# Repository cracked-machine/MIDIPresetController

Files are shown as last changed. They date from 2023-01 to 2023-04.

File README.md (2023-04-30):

# MIDIPresetController

This is a simple MIDI controller for Guitar FX pedals. An [STM32L011D4](HW/techdocs/stm32l011d4_datasheet.pdf) is used to detect stomp switch presses by the user and output MIDI signals via a DIN5 connector.

The project is designed to fit into a [Hammond 1455J1602](HW/techdocs/Hammond_1455J1602BK_enclosure.pdf) enclosure. 

3D models can be found here for the [end plate bezel](https://3dviewer.net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) and [main extrusion](https://3dviewer.net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)

This is an extruded alu case. The PCB slides in from one side.  

The stomp switches are panel mounted on the front side of the enclosure with connecting wires to rear of the PCB (via molex KK254 connectors)





It is powered by a 3v3 CR2032 cell, held by a battery clip, which is mounted on the rear side of the PCB. Internal voltage reference of the MCU is used to measure remaining battery. An LED mounted on the front of the PCB and connected to GPIO indicates low battery power to the user.

The MIDI channel can be selected using the DIP switch on the rear side of the PCB.  The MIDI output connector (DIN5) is mounted to the end plate bezel of the enclosure

A 10-pin ARM SWD programming connector is mounted to the rear of the PCB. 

A removable "belly plate" on the enclosure provides access to the battery, MIDI DIP switch and SWD connector.  

### Development Environment

YOu can run this project from within a container and program the board via a Segger JLink. This uses `JLinkRemoteServer` to establish a connect between the container environment and the device connected to the `host` PC. To enable this connection, run the follow command on the __host__ terminal:

```
JLinkRemoteServer --select USB
```

See [stm32_dev_docker/README.md](https://github.com/cracked-machine/stm32_dev_docker) for instructions on using the `development environment` for this project.

Note: this project is currently configured for a specific version of CMake and ARM compiler. The paths are hard-coded in the project [here](.vscode/settings.json)

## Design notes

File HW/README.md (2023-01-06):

# MIDIPresetController

This is the doc for the [hardware project files](KicadProject)

This project has the following dependencies to [KicadLibrary](HW/KicadLibrary):

- BATTERY/GenericCoinCellHolders/GenericCoinCellHolders

## Schematic 

1. System



2. Input 



3. MCU



4. Output



## Pinout 
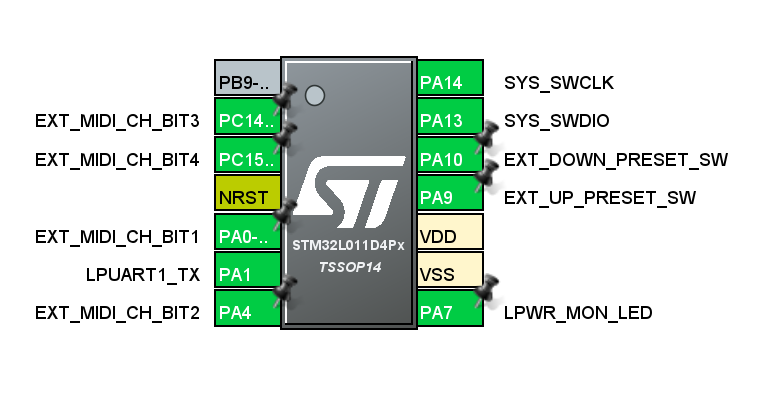
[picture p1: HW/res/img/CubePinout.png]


## PCB

1. Front

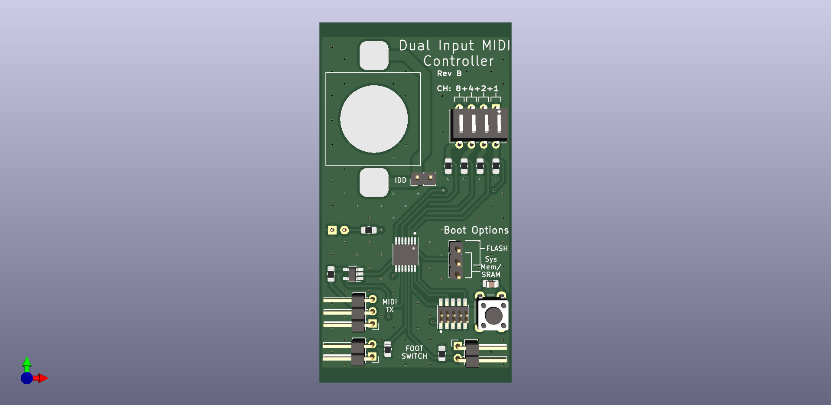
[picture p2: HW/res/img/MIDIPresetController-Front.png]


2. Back

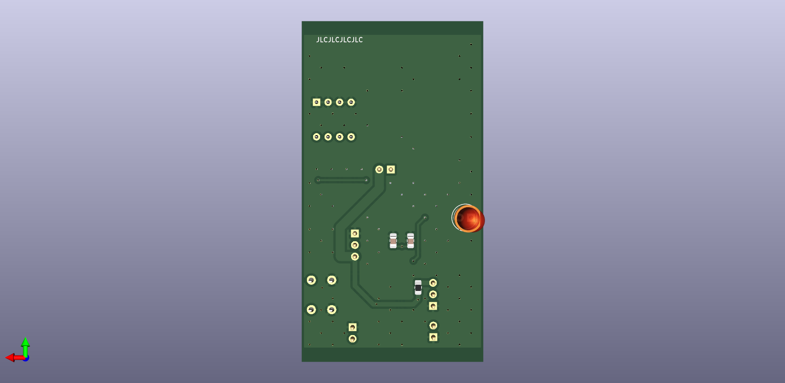
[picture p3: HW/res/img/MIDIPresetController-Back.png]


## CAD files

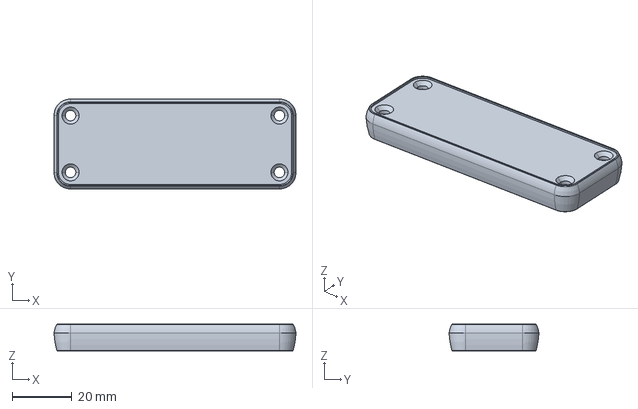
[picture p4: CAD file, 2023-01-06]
HW/res/3d/1455J1602/J Bezel Closed.stp
81.1 x 30.1 x 9.00 mm

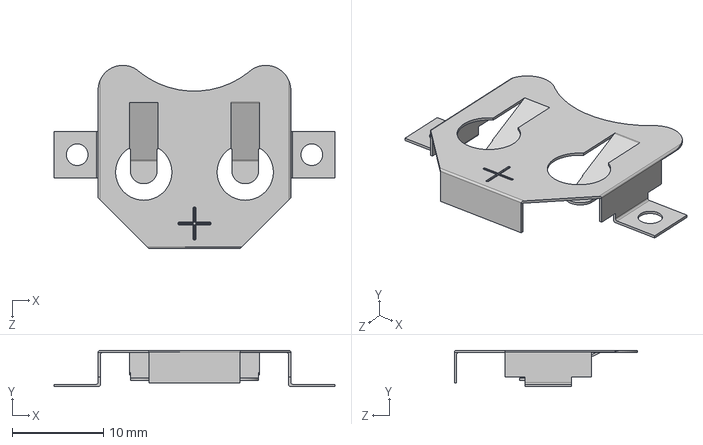
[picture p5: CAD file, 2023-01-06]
HW/res/3d/CR3Holder002.step
30.7 x 3.96 x 20.1 mm

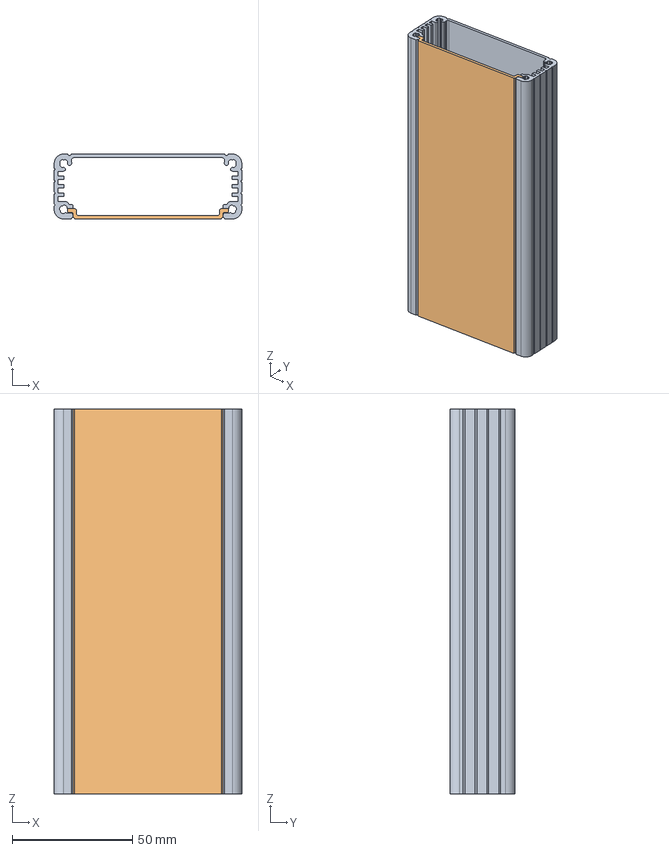
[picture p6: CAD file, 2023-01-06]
HW/res/3d/1455J1602/J Extrusion 160mm.stp
78.0 x 27.0 x 160.0 mm

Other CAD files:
HW/res/3d/1455J1602/J Bezel Closed.igs
HW/res/3d/1455J1602/J Extrusion 160mm.igs

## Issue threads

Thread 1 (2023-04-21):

Enable timer for debounce

cracked-machine, 2023-04-21:
1. Enable TIM21 peripheral.  Interrupts are not needed.

```
    RCC->APB2ENR |= RCC_APB2ENR_TIM21EN_Msk;                            // enable the APB2 bus clock used by TIM21
    TIM21->CR1 |= (TIM_CR1_ARPE_Msk);                                   // preload buffer
    TIM21->PSC = 0xFFFF;                                                    // prescaler
    TIM21->ARR = 0xFFFFFFFE;                                            // auto-reload value

    // TIM21->DIER |= (TIM_DIER_UIE_Msk);                                  // enable interrupts
    // NVIC_EnableIRQ(TIM21_IRQn);
    // NVIC_SetPriority(TIM21_IRQn,_TIM21_ISR_PRIORITY);

    TIM21->CR1 |= (TIM_CR1_CEN_Msk);                                    // start the timer
```

2. Add debounce code

```
# global vars
const volatile uint32_t FOOTSW_DEBOUNCE_COOLDOWN{ 100 };
volatile uint32_t footsw_down_prev_cnt = 0;

void PERIPH_ISR()
{
        uint32_t tmp_cnt = TIM21->CNT;
        if ((tmp_cnt - footsw_down_prev_cnt) > FOOTSW_DEBOUNCE_COOLDOWN)
        {
            // do stuff
        }
        footsw_down_prev_cnt = tmp_cnt;

}
```

cracked-machine, 2023-04-21:
f452b76562065cfc2fa9082e9c51a1b93853bc89
e565cd7474d71bd6fbaafc158bc97176621c218a

Closed 2023-04-21.

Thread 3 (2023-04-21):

Enable VREF for battery level monitoring

cracked-machine, 2023-04-21:

cracked-machine, 2023-04-21:
LED should flash when low battery threshold is reached.

- The internal voltage reference (V REFINT ) provides a stable (bandgap) voltage output for the
ADC and comparators. V REFINT is internally connected to the ADC V IN[17] input channel.

- VREFEN bit must be set to enable the conversion of ADC V IN[17] (V REFINT).
- During the manufacturing process, the calibration data of the temperature sensor and the
internal voltage reference are stored in the system memory area. The user application can
then read them and use them to improve the accuracy of the temperature sensor or the
internal reference.

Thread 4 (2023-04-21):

Enable low power mode

cracked-machine, 2023-04-21:
- STOP mode lowers current consumption to ~0.5uA.
- Can be woken from EXTI (i.e. footswitch). Possible startup delay.

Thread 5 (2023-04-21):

Fit TVS diodes to footswitch and dipswitch inputs

cracked-machine, 2023-04-21:

Closed 2023-04-30.

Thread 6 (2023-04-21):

Move `J3` footprint away from NRST `SW1` footprint.

cracked-machine, 2023-04-21:
- Workaround: It is still possible to plug debug cable into `J3` without it being obstructed by `SW1`.

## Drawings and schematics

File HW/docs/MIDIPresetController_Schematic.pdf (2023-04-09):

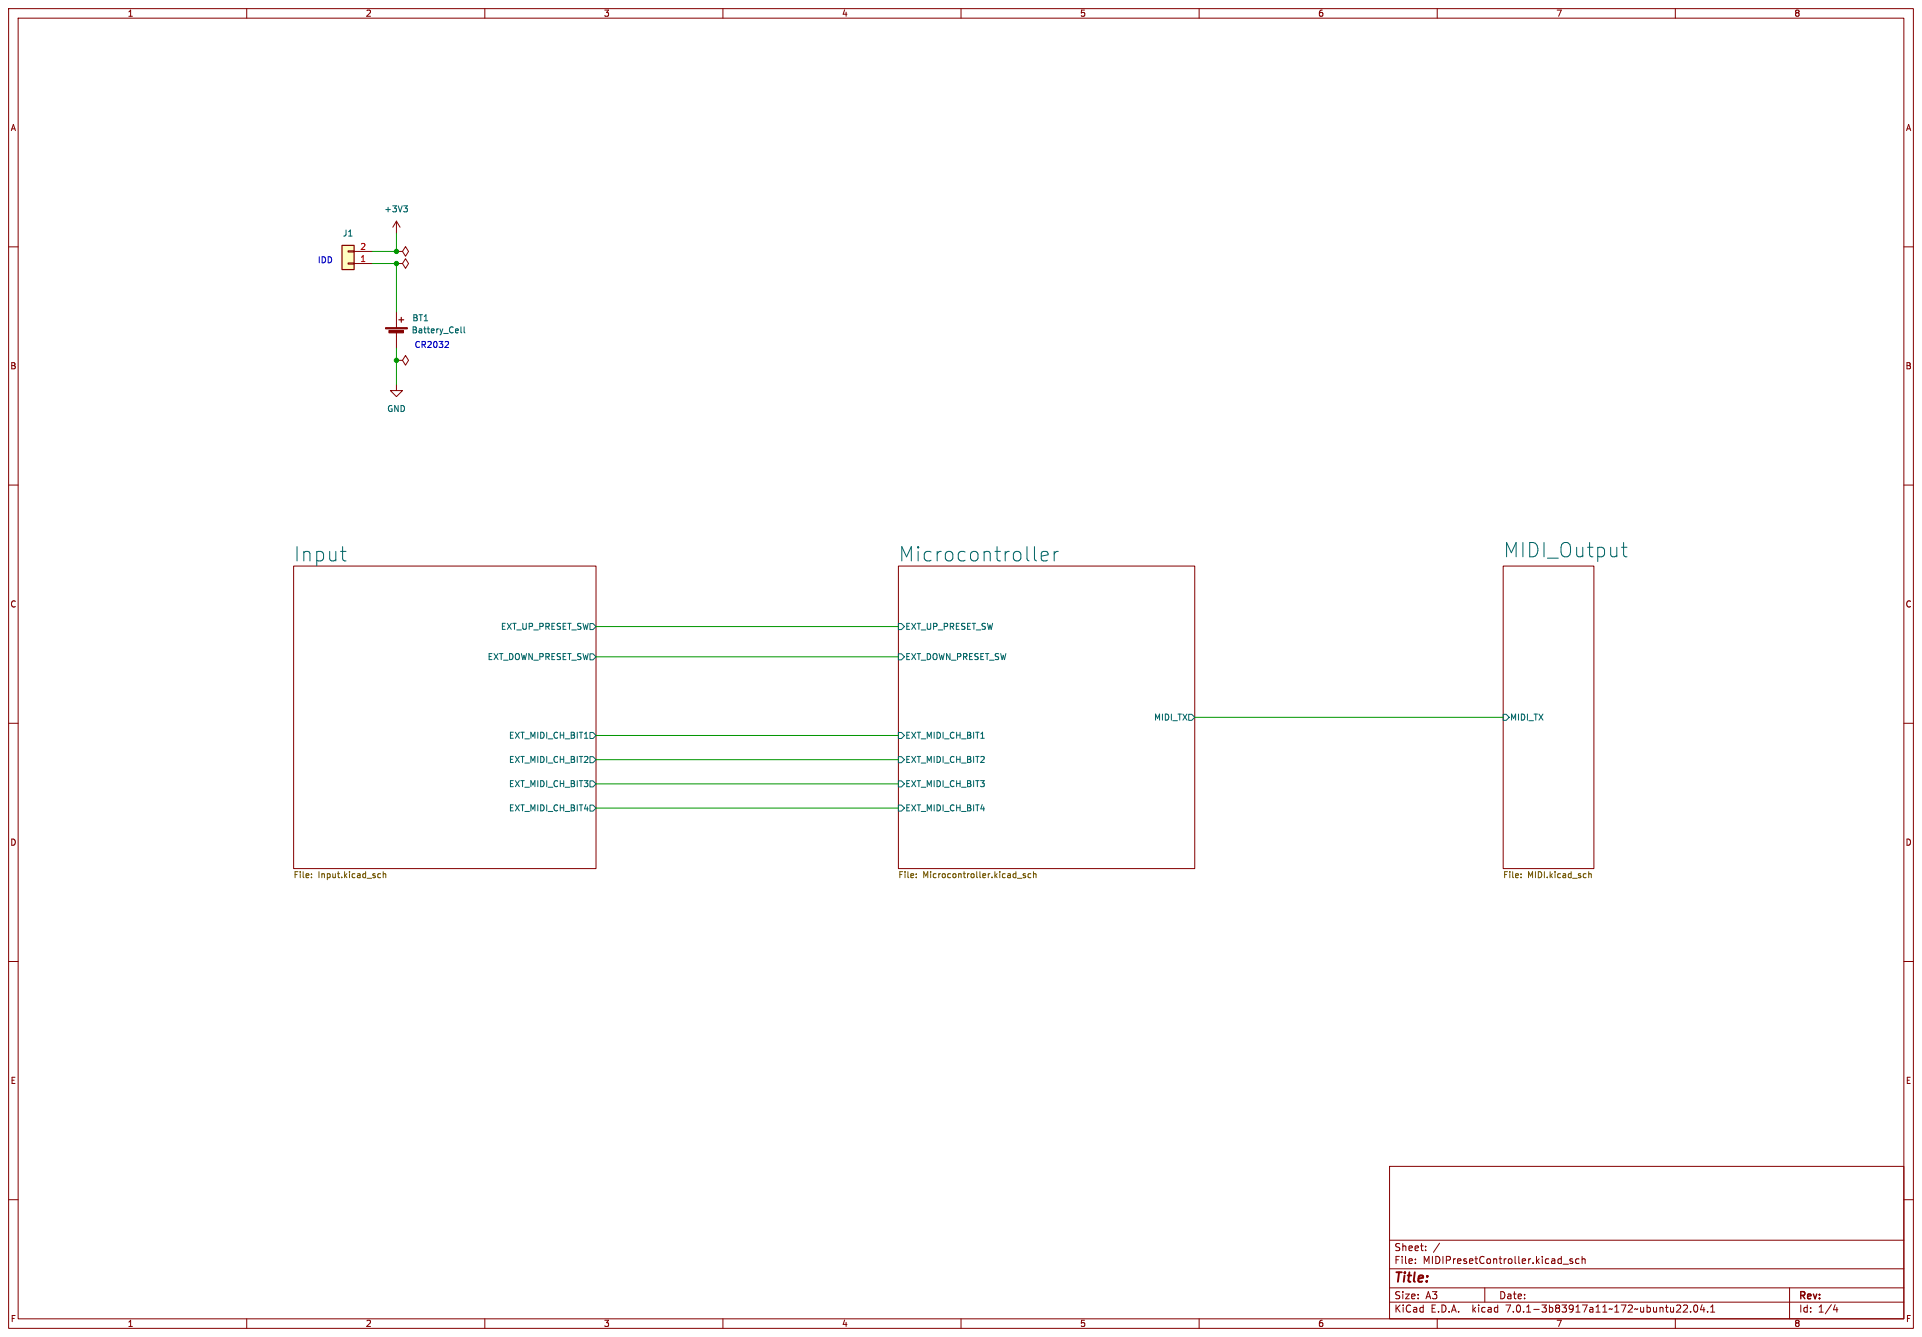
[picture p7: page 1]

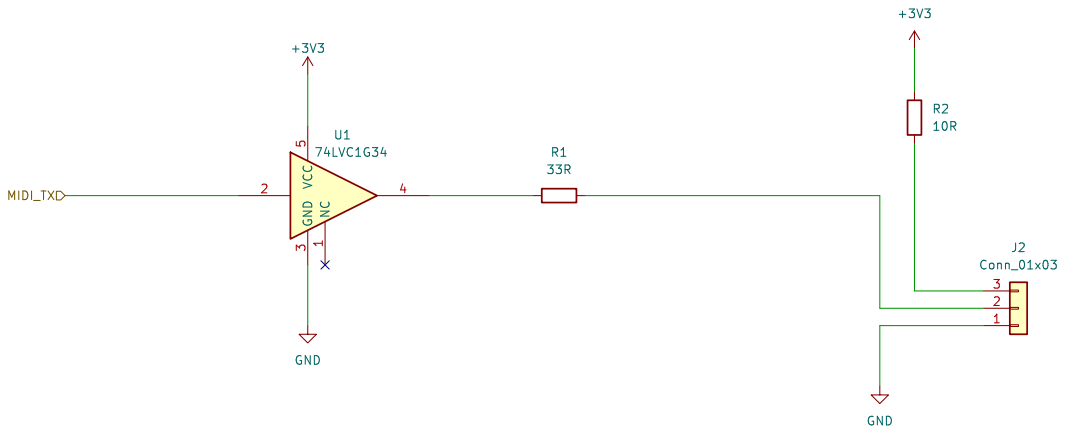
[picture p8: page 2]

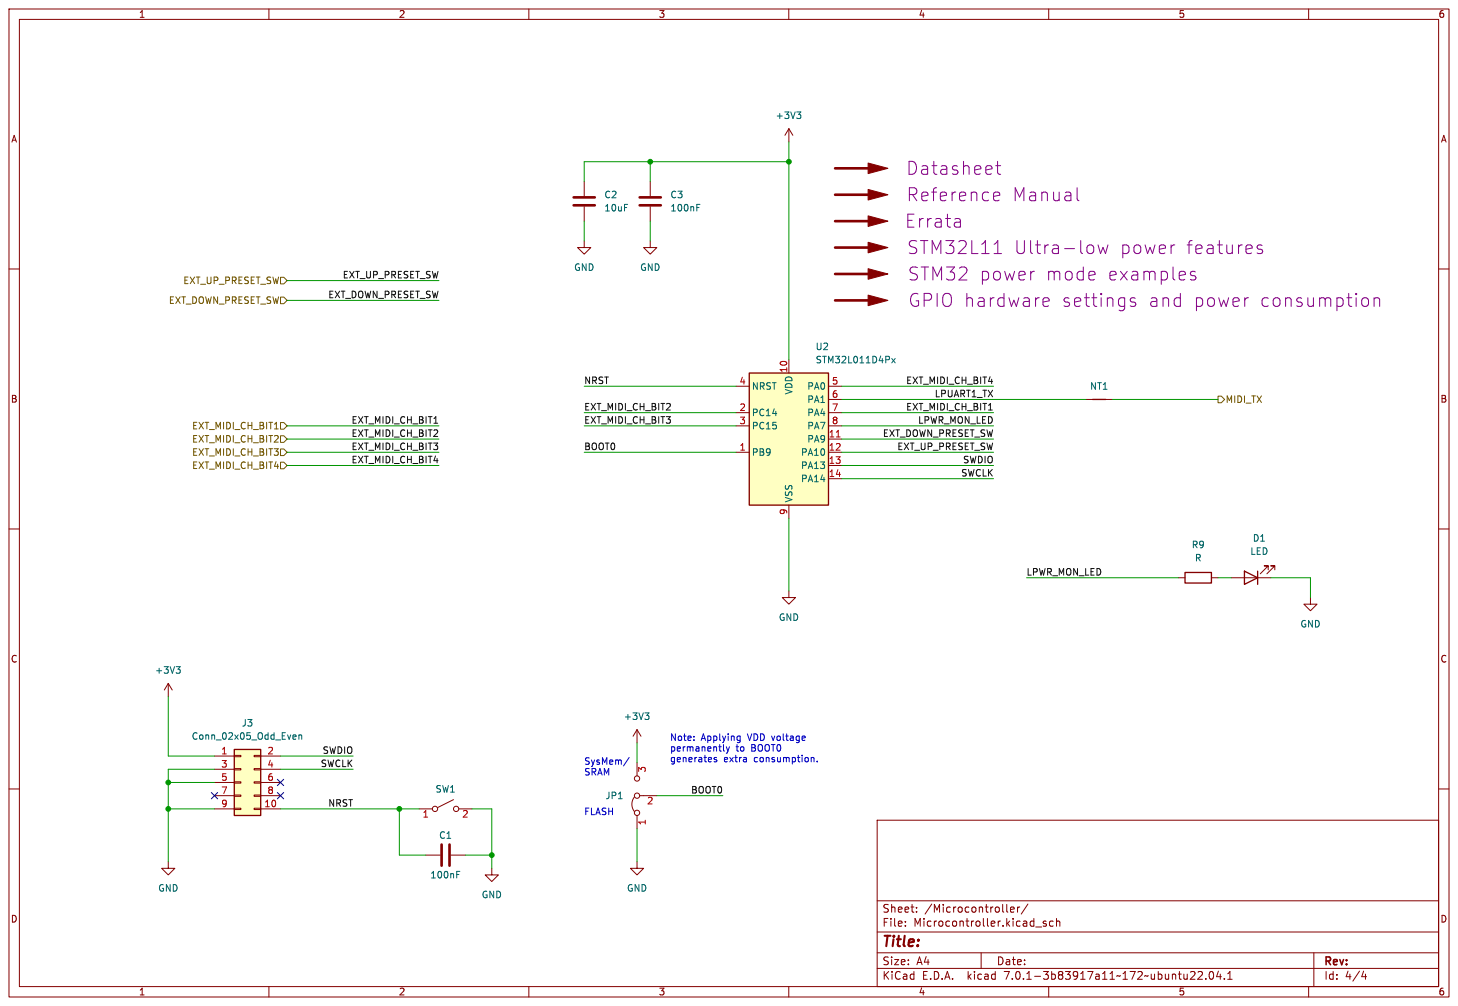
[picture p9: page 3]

Note: Applying VDD voltage

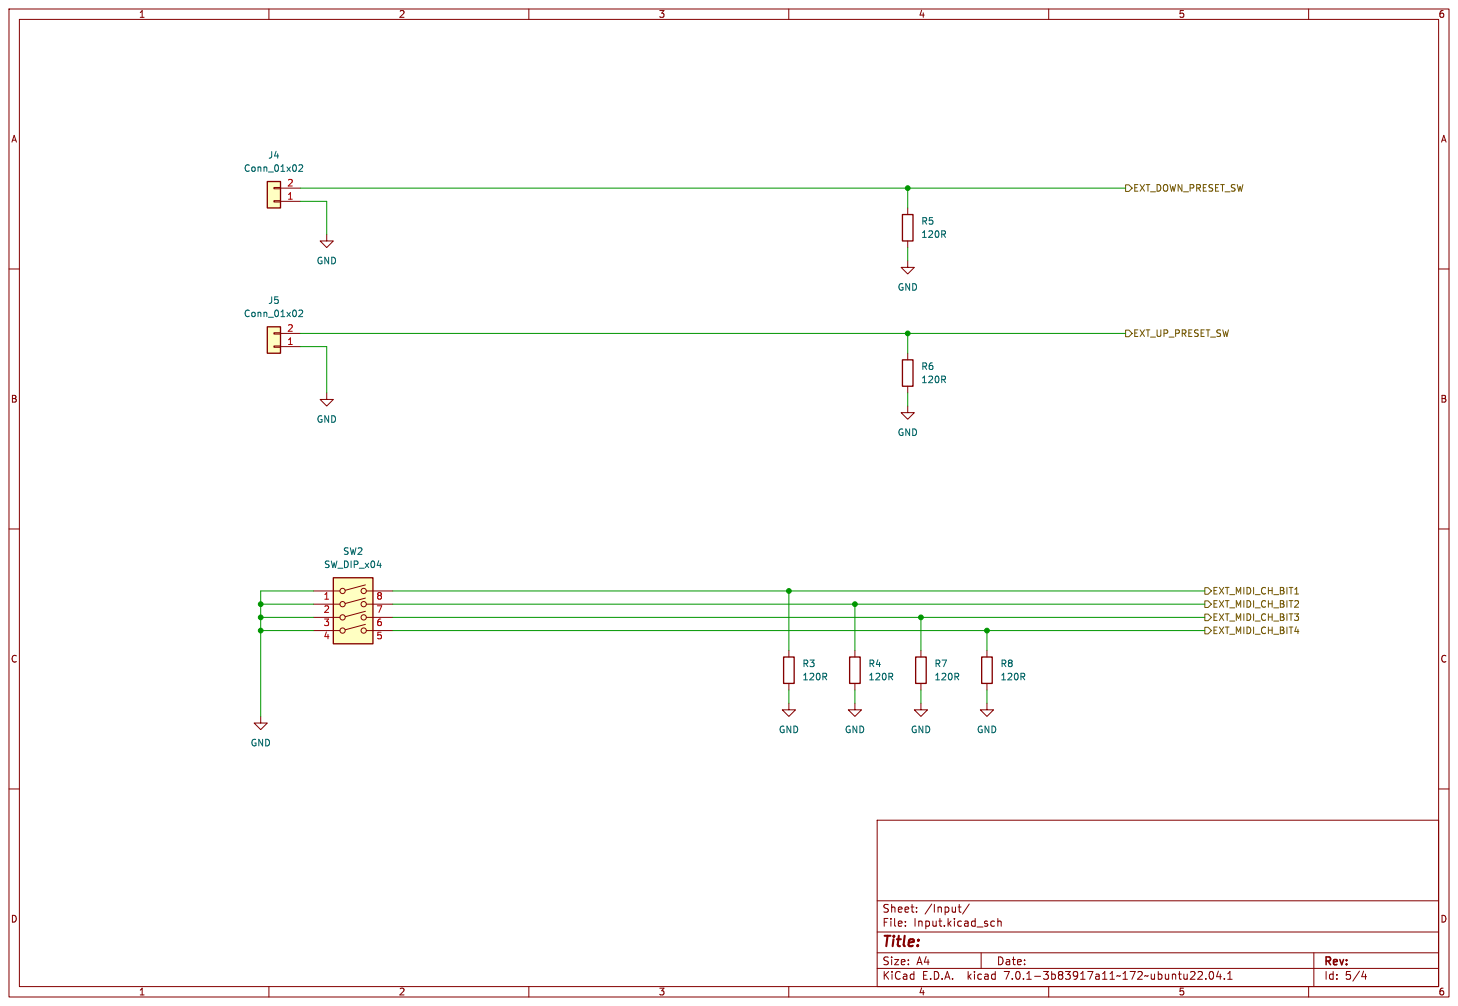
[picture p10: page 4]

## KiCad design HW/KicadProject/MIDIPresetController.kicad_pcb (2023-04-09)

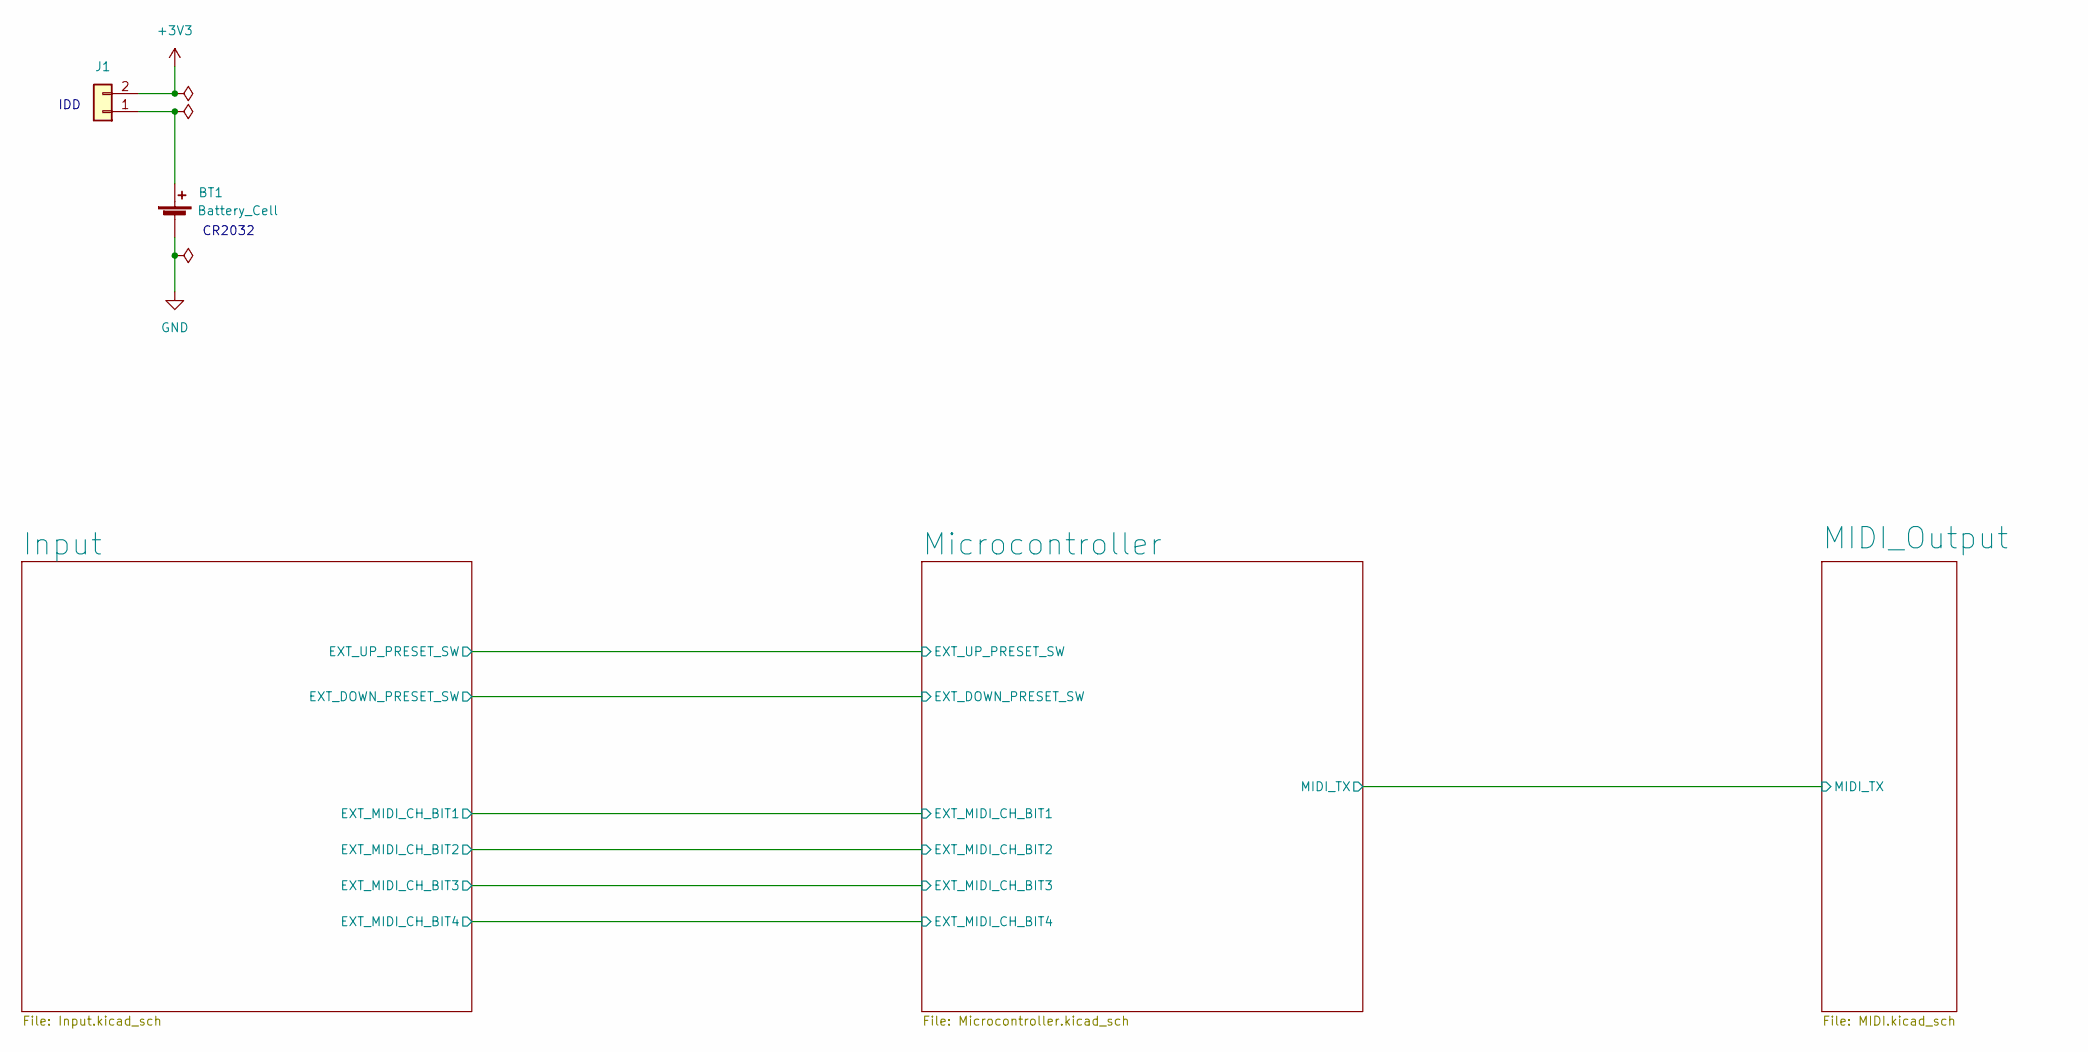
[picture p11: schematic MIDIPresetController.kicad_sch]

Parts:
BT1: Battery_Cell; CR2032
J1: Conn_01x02; PinHeader_1x02_P2.54mm_Vertical

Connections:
+3V3: J1.2; also elsewhere on the board
GND: BT1.2 (-); also elsewhere on the board
unnamed: BT1.1 (+), J1.1

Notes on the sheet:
CR2032
IDD

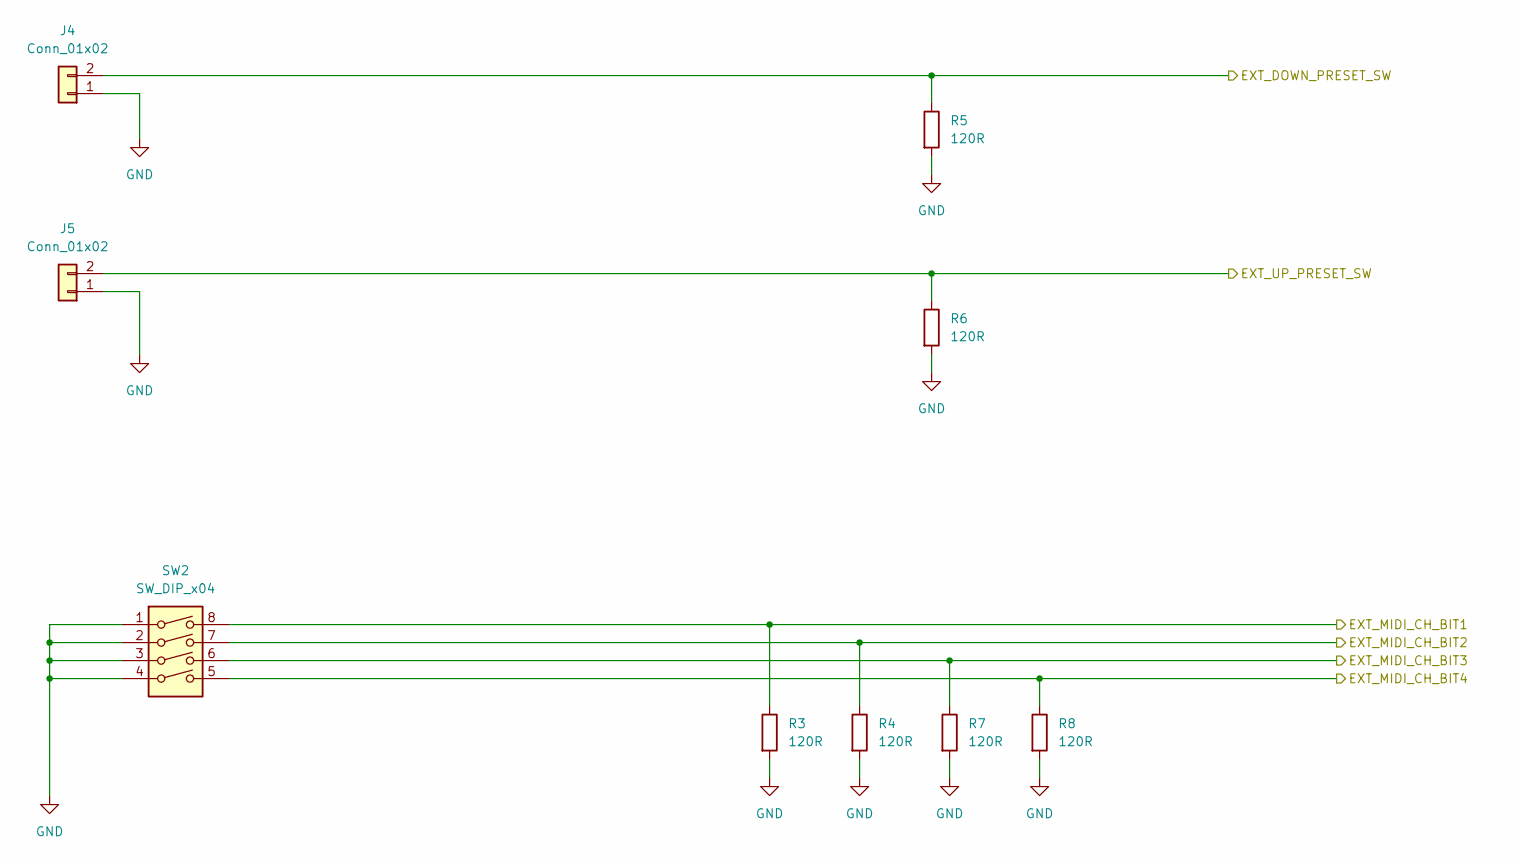
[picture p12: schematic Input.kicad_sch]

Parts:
J4, J5: Conn_01x02; PinHeader_1x02_P2.54mm_Horizontal
R3, R4, R5, R6, R7, R8: 120R; R_0805_2012Metric_Pad1.20x1.40mm_HandSolder
SW2: SW_DIP_x04; SW_DIP_SPSTx04_Slide_6.7x11.72mm_W7.62mm_P2.54mm_LowProfile

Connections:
/Microcontroller/EXT_DOWN_PRESET_SW: J4.2, R5.1; also elsewhere on the board
/Microcontroller/EXT_MIDI_CH_BIT1: R3.1, SW2.8; also elsewhere on the board
/Microcontroller/EXT_MIDI_CH_BIT2: R4.1, SW2.7; also elsewhere on the board
/Microcontroller/EXT_MIDI_CH_BIT3: R7.1, SW2.6; also elsewhere on the board
/Microcontroller/EXT_MIDI_CH_BIT4: R8.1, SW2.5; also elsewhere on the board
/Microcontroller/EXT_UP_PRESET_SW: J5.2, R6.1; also elsewhere on the board
GND: J4.1, J5.1, R3.2, R4.2, R5.2, R6.2, R7.2, R8.2, SW2.1, SW2.2, SW2.3, SW2.4; also elsewhere on the board

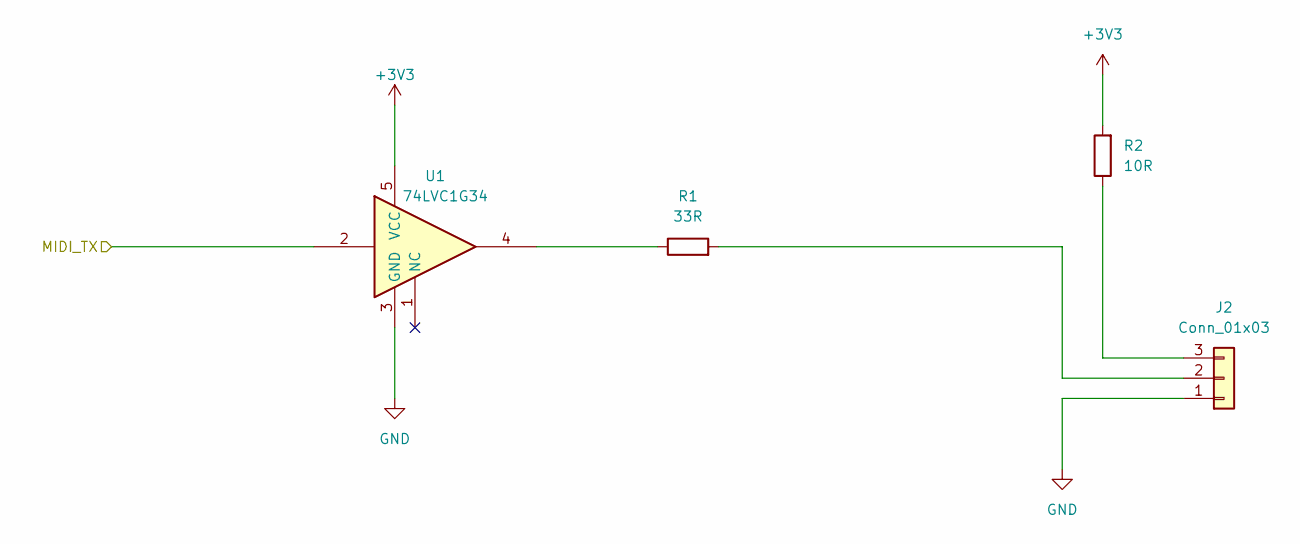
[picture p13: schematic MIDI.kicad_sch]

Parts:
J2: Conn_01x03; PinHeader_1x03_P2.54mm_Horizontal
R1: 33R; R_0805_2012Metric_Pad1.20x1.40mm_HandSolder
R2: 10R; R_0805_2012Metric_Pad1.20x1.40mm_HandSolder
U1: 74LVC1G34; SOT-23-5_HandSoldering

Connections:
+3V3: R2.2, U1.5 (VCC); also elsewhere on the board
/MIDI_Output/MIDI_TX: U1.2; also elsewhere on the board
GND: J2.1, U1.3 (GND); also elsewhere on the board
unnamed: J2.2, R1.2
unnamed: J2.3, R2.1
unnamed: R1.1, U1.4

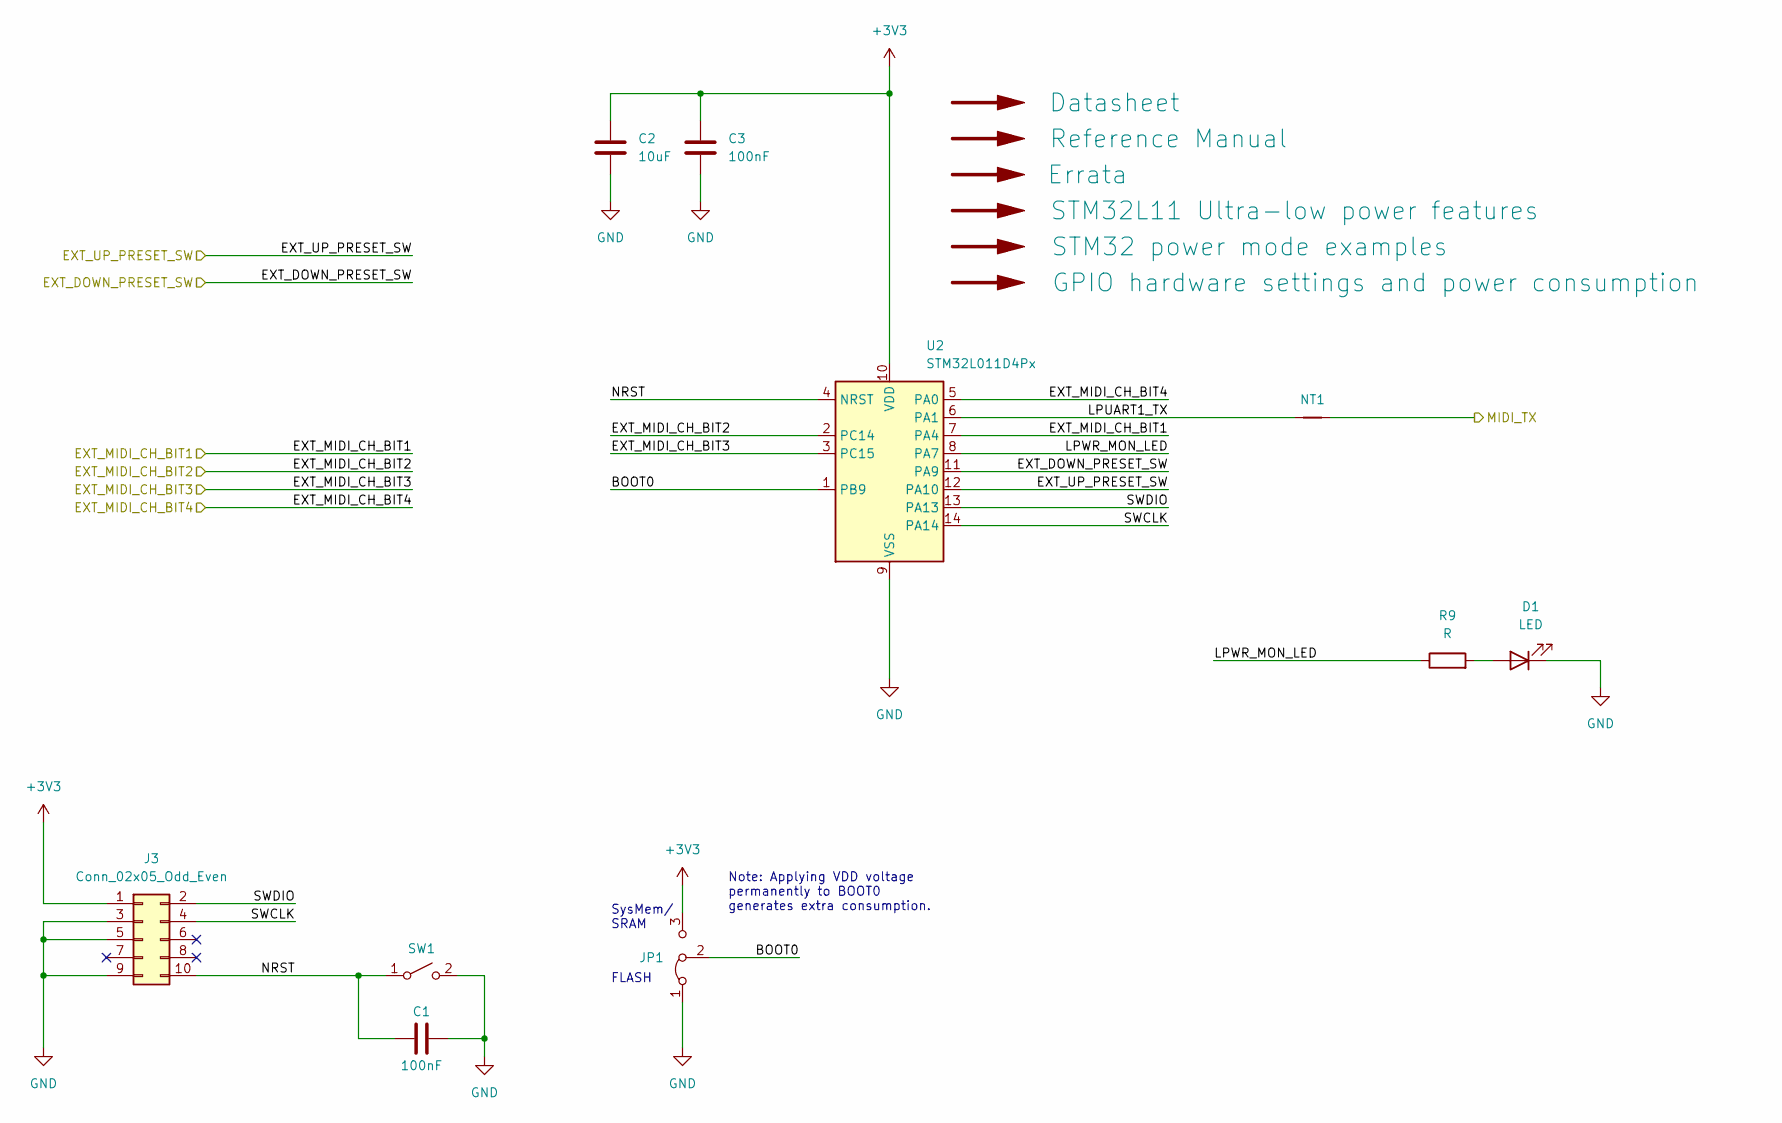
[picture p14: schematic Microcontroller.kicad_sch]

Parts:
C1, C3: 100nF; C_0805_2012Metric_Pad1.18x1.45mm_HandSolder
C2: 10uF; C_0805_2012Metric_Pad1.18x1.45mm_HandSolder
D1: LED; LED_D5.0mm
J3: Conn_02x05_Odd_Even; PinHeader_2x05_P1.27mm_Vertical_SMD
JP1: Jumper_3_Bridged12; PinHeader_1x03_P2.54mm_Vertical
NT1: NetTie_2; NetTie-2_SMD_Pad0.5mm
R9: R; R_0805_2012Metric_Pad1.20x1.40mm_HandSolder
SW1: SW_SPST; SW_PUSH_6mm
U2: STM32L011D4Px; TSSOP-14_4.4x5mm_P0.65mm

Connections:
+3V3: C2.1, C3.1, J3.1, JP1.3 (B), U2.10 (VDD); also elsewhere on the board
/MIDI_Output/MIDI_TX: NT1.2; also elsewhere on the board
/Microcontroller/BOOT0: JP1.2 (C), U2.1 (PB9)
/Microcontroller/EXT_DOWN_PRESET_SW: U2.11 (PA9); also elsewhere on the board
/Microcontroller/EXT_MIDI_CH_BIT1: U2.7 (PA4); also elsewhere on the board
/Microcontroller/EXT_MIDI_CH_BIT2: U2.2 (PC14); also elsewhere on the board
/Microcontroller/EXT_MIDI_CH_BIT3: U2.3 (PC15); also elsewhere on the board
/Microcontroller/EXT_MIDI_CH_BIT4: U2.5 (PA0); also elsewhere on the board
/Microcontroller/EXT_UP_PRESET_SW: U2.12 (PA10); also elsewhere on the board
/Microcontroller/LPUART1_TX: NT1.1, U2.6 (PA1)
/Microcontroller/LPWR_MON_LED: R9.1, U2.8 (PA7)
/Microcontroller/NRST: C1.1, J3.10, SW1.1 (A), U2.4 (NRST)
/Microcontroller/SWCLK: J3.4, U2.14 (PA14)
/Microcontroller/SWDIO: J3.2, U2.13 (PA13)
GND: C1.2, C2.2, C3.2, D1.1 (K), J3.3, J3.5, J3.9, JP1.1 (A), SW1.2 (B), U2.9 (VSS); also elsewhere on the board
unnamed: D1.2 (A), R9.2

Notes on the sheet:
SysMem/ SRAM
FLASH
Note: Applying VDD voltage permanently to BOOT0 generates extra consumption.

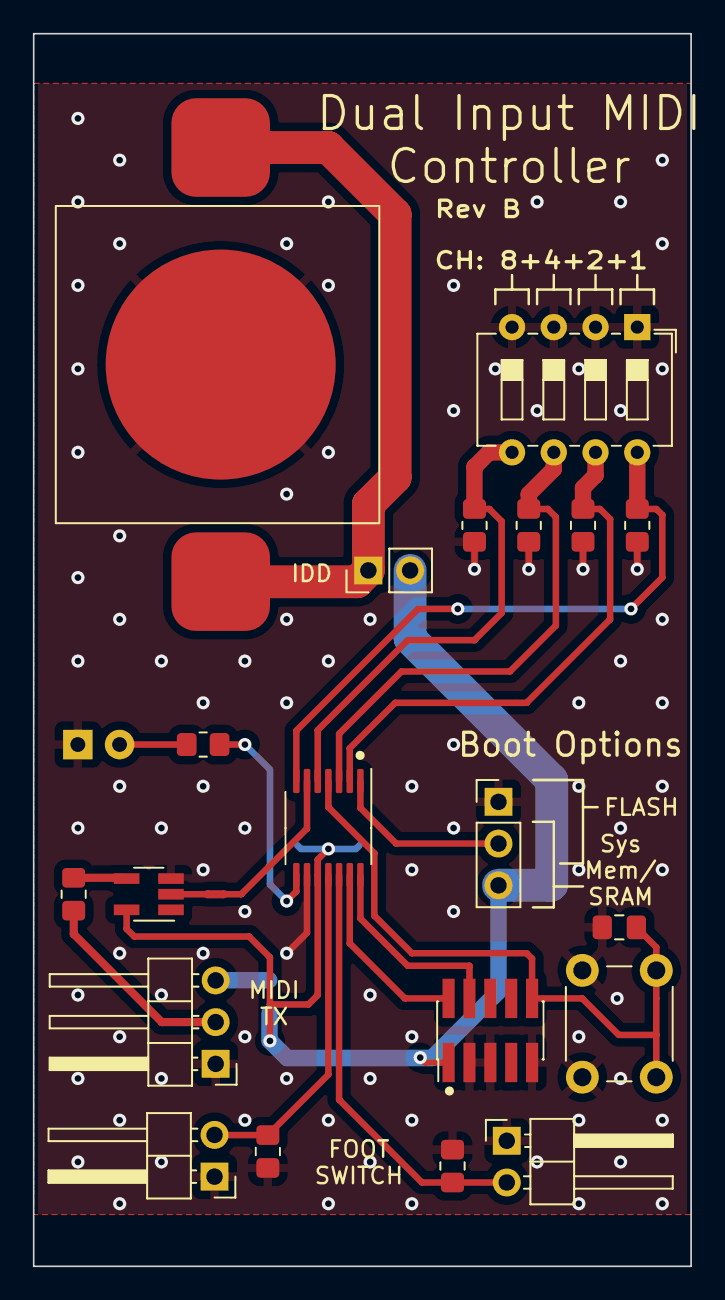
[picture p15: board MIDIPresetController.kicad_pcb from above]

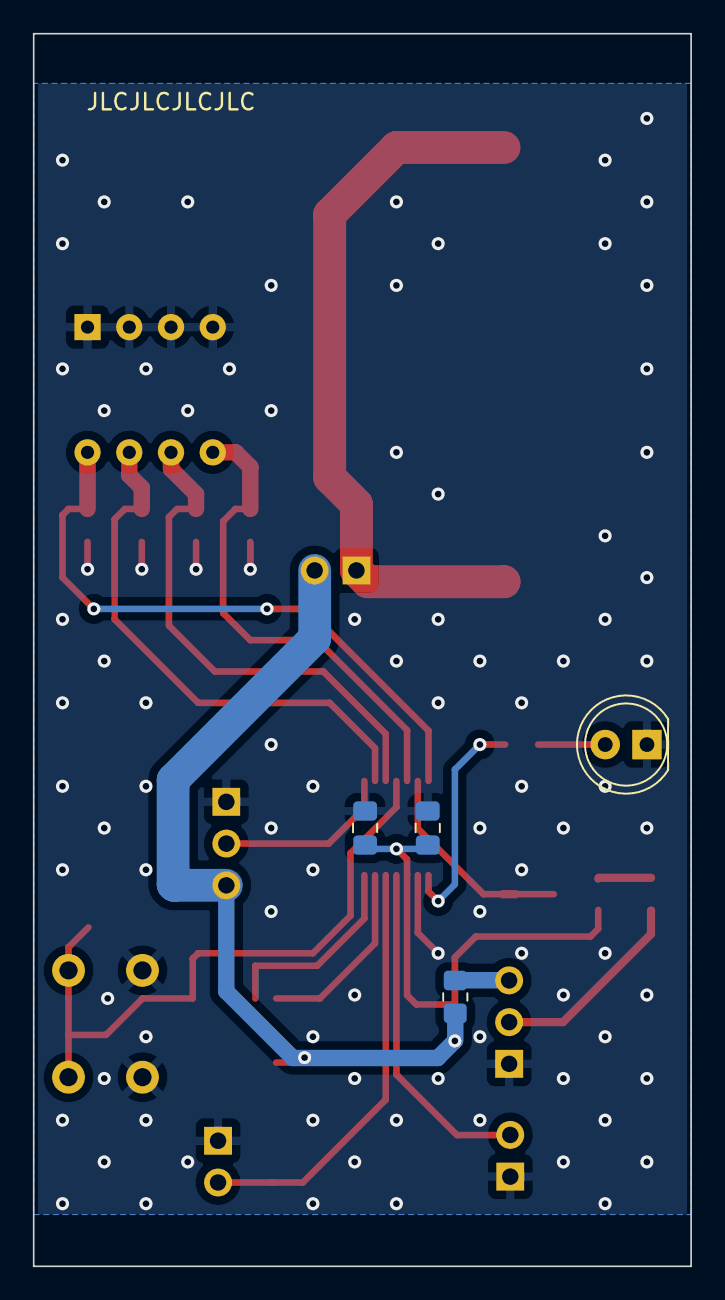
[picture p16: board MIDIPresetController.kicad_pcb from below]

Board: 2 copper layers, 40.0 x 75.0 mm, 25 parts (4 on the bottom side), 20 nets.

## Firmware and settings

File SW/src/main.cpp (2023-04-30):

#include "main.hpp"

#include "stm32l011xx.h"
#if DEBUG
    #include <SEGGER_RTT.h>
#endif

#include <led.hpp>
#include <rcc.hpp>


#define UART_DIV_LPUART(__PCLK__, __BAUD__)      (((((uint64_t)(__PCLK__)*256U)) + ((__BAUD__)/2U)) / (__BAUD__))


const uint32_t _LPUART_ISR_PRIORITY = 0U;
const uint32_t _TIM21_ISR_PRIORITY = 0U;
const uint32_t _EXTI_ISR_PRIORITY = 0U;

void setup()
{
  
    // HCLK //
    //////////
    RCC->CR |= RCC_CR_HSION_Msk;                                // enable HSI16 clk source
    RCC->CFGR |= RCC_CFGR_PLLSRC_HSI;                           // set the PLL source mux to HSI16
    
    RCC->CR &= (uint32_t)(~RCC_CR_PLLON);                       // Disable the PLL    
    while((RCC->CR & RCC_CR_PLLRDY) != 0) { }                   // Wait for PLLRDY to be cleared

    FLASH->ACR |= FLASH_ACR_LATENCY;                            // Set latency to 1 wait state
    RCC->CFGR |= (RCC_CFGR_PLLMUL3 | RCC_CFGR_PLLDIV2);         // Set the PLL to 24MHz (assuming RCC_CFGR_HPRE_DIV1 is set below)

    RCC->CFGR &= ~(RCC_CFGR_HPRE_DIV512);                       // mask write all four bits to zero
    RCC->CFGR |= (RCC_CFGR_HPRE_DIV1);                          // 24Mhz
    // RCC->CFGR |= (RCC_CFGR_HPRE_DIV2);                          // 12MHz
    // RCC->CFGR |= (RCC_CFGR_HPRE_DIV4);                          // 6Mhz
    // RCC->CFGR |= (RCC_CFGR_HPRE_DIV8);                          // 3MHz
    // RCC->CFGR |= (RCC_CFGR_HPRE_DIV16);                         // 1.5MHz
    // RCC->CFGR |= (RCC_CFGR_HPRE_DIV64);                         // 0.375MHz
    // RCC->CFGR |= (RCC_CFGR_HPRE_DIV128);                        // 0.1875MHz
    // RCC->CFGR |= (RCC_CFGR_HPRE_DIV256);                        // 0.09375MHz
    // RCC->CFGR |= (RCC_CFGR_HPRE_DIV512);                        // 0.046875MHz
    
    RCC->CR |= RCC_CR_PLLON;                                    // Enable the PLL
    while ((RCC->CR & RCC_CR_PLLRDY) == 0) { }                  // Wait until PLLRDY is set
    
    RCC->CFGR |= (uint32_t) (RCC_CFGR_SW_PLL);                  // Select PLL as system clock
    while ((RCC->CFGR & RCC_CFGR_SWS) != RCC_CFGR_SWS_PLL) { }  // Wait untill PLL is switched on


    RCC->IOPENR |= RCC_IOPENR_GPIOAEN;                                  // enable GPIO bus clock (used by multiple porta pins)
    RCC->IOPENR |= RCC_IOPENR_GPIOCEN;                                  // enable GPIO bus clock (used by multiple porta pins)
    
    // LED //
    /////////
    GPIOA->MODER |= (GPIO_MODER_MODE7_0);                               // config PA7 as output (0x01)
    GPIOA->MODER &= ~(GPIO_MODER_MODE7_1);
    GPIOA->OTYPER &= ~(GPIO_OTYPER_OT_7);                               // setup p7 as pushpull, highspeed, no PU/PD
    GPIOA->OSPEEDR |= (GPIO_OSPEEDER_OSPEED7_Msk);
    GPIOA->PUPDR &= ~(GPIO_PUPDR_PUPD7_Msk);    

    // EXTI //
    //////////
    RCC->APB2ENR |= RCC_APB2ENR_SYSCFGEN_Msk; 
    SYSCFG->EXTICR[2] |= (SYSCFG_EXTICR3_EXTI9_PA);                     // map Port A GPIOs to EXTI9
    SYSCFG->EXTICR[2] |= (SYSCFG_EXTICR3_EXTI10_PA);                    // map Port A GPIOs to EXTI10
                                                                        
    // PA10
    GPIOA->MODER &= ~((GPIO_MODER_MODE10_0) | (GPIO_MODER_MODE10_1));   // setup pa10 gpio as input (0x00)
    GPIOA->PUPDR |= (GPIO_PUPDR_PUPD10_0);                              // set pa10 gpio pullup (0x01)
    GPIOA->PUPDR &= ~(GPIO_PUPDR_PUPD10_1);
    EXTI->IMR |= EXTI_IMR_IM10_Msk;                                     // enable interupt request in interrupt mask register
    EXTI->FTSR |= EXTI_FTSR_FT10_Msk;                                   // program trigger resistors with edge detection

    // PA9 
    GPIOA->MODER &= ~((GPIO_MODER_MODE9_0) | (GPIO_MODER_MODE9_1));     // setup pa10 gpio as input (0x00)
    GPIOA->PUPDR |= (GPIO_PUPDR_PUPD9_0);                               // set pa10 gpio pullup (0x01)
    GPIOA->PUPDR &= ~(GPIO_PUPDR_PUPD9_1);
    EXTI->IMR |= EXTI_IMR_IM9_Msk;                                      // enable interupt request in interrupt mask register
    EXTI->FTSR |= EXTI_FTSR_FT9_Msk;                                    // program trigger resistors with edge detection

    // PA4 - EXT_MIDI_CH_BIT1
    GPIOA->MODER &= ~((GPIO_MODER_MODE4_0) | (GPIO_MODER_MODE4_1));     // setup PA4 gpio as input (0x00)
    GPIOA->PUPDR |= (GPIO_PUPDR_PUPD4_0);                               // set pa4 gpio pullup (0x01)
    GPIOA->PUPDR &= ~(GPIO_PUPDR_PUPD4_1);
    
    // PC14 - EXT_MIDI_CH_BIT2
    GPIOC->MODER &= ~((GPIO_MODER_MODE14_0) | (GPIO_MODER_MODE14_1));   // setup PC14 gpio as input (0x00)
    GPIOC->PUPDR |= (GPIO_PUPDR_PUPD14_0);                              // set pc14 gpio pullup (0x01)
    GPIOC->PUPDR &= ~(GPIO_PUPDR_PUPD14_1);

    // PC15 - EXT_MIDI_CH_BIT3
    GPIOC->MODER &= ~((GPIO_MODER_MODE15_0) | (GPIO_MODER_MODE15_1));   // setup PC15 gpio as input (0x00)
    GPIOC->PUPDR |= (GPIO_PUPDR_PUPD15_0);                              // set pc15 gpio pullup (0x01)
    GPIOC->PUPDR &= ~(GPIO_PUPDR_PUPD15_1);
    
    // PA0 - EXT_MIDI_CH_BIT4
    GPIOA->MODER &= ~((GPIO_MODER_MODE0_0) | (GPIO_MODER_MODE0_1));     // setup PA0 gpio as input (0x00)
    GPIOA->PUPDR |= (GPIO_PUPDR_PUPD0_0);                               // set pa0 gpio pullup (0x01)
    GPIOA->PUPDR &= ~(GPIO_PUPDR_PUPD0_1);
    
    NVIC_EnableIRQ(EXTI4_15_IRQn);                                      // configure nvic irq channel and prio
    NVIC_SetPriority(EXTI4_15_IRQn, _EXTI_ISR_PRIORITY); 

    // LPUART //
    ////////////
    GPIOA->MODER |= (GPIO_MODER_MODE1_1);                               // Set PA1 as alt func (0x10) 
    GPIOA->MODER &= ~(GPIO_MODER_MODE1_0);
    volatile uint32_t GPIOA_AF_LPUART = 0x6;
    GPIOA->AFR[0] |= (GPIOA_AF_LPUART << GPIO_AFRL_AFSEL1_Pos);         // Set alt func on pin pa1 to lpuart1
    GPIOA->OSPEEDR |= GPIO_OSPEEDER_OSPEED1_Msk;                        // "very fast" speed
    
    RCC->APB1ENR |= RCC_APB1ENR_LPUART1EN_Msk;                          // enable the APB1 bus clock used by LPUART
    RCC->CCIPR &= ~(RCC_CCIPR_LPUART1SEL_1 | RCC_CCIPR_LPUART1SEL_0);   // Reset. APB/PCLK (HSI16 via PLL and AHB PSC) selected as LPUART source
    // RCC->CCIPR |= (RCC_CCIPR_LPUART1SEL_0);                             // SystemClock (HSI16 via PLL) selected as LPUART source
    // RCC->CCIPR |= (RCC_CCIPR_LPUART1SEL_1);                             // direct HSI16 (No Multipliers or PSCs) selected as LPUART source
    
    LPUART1->CR1 &= ~((USART_CR1_M0_Msk) | (USART_CR1_M1_Msk));          // 1 start bit, 8 data bits, n stop bits
    uint32_t pclk = get_clk_freq();                                     // baud rate
    uint32_t baudrate = 31250U;    
    LPUART1->BRR = (uint32_t)UART_DIV_LPUART(pclk, baudrate);                               
    LPUART1->CR2 &= ~(USART_CR2_STOP_Msk);                               // 1 stop bit
    LPUART1->CR1 &= ~(USART_CR1_PCE_Msk);                                // no parity for MIDI
    LPUART1->CR2 &= ~(USART_CR2_MSBFIRST_Msk);                           // LSB first
    // LPUART1->CR1 |=  ( USART_CR1_TXEIE_Msk );                              // Enable TXE (tx data reg transferred) interrupts
                    // | USART_CR1_TCIE_Msk);                                // Enable TC (transmission complete) interrupts
                    // | USART_CR3_EIE_Msk );                              // Enable error interrupts
    LPUART1->CR1 |= (USART_CR1_UE_Msk);                                  // enable the LPUART
    LPUART1->CR1 |= (USART_CR1_TE_Msk);                                  // send idle frame as first transmission
    NVIC_SetPriority(LPUART1_IRQn, _LPUART_ISR_PRIORITY);
    NVIC_EnableIRQ(LPUART1_IRQn);

    // TIMER21 //
    /////////////
    RCC->APB2ENR |= RCC_APB2ENR_TIM21EN_Msk;                            // enable the APB2 bus clock used by TIM21
    TIM21->CR1 |= (TIM_CR1_ARPE_Msk);                                   // preload buffer
    TIM21->PSC = 0xFFFF;                                                    // prescaler
    TIM21->ARR = 0xFFFFFFFE;                                            // auto-reload value
    // TIM21->PSC = 0x1;                                                    // prescaler
    // TIM21->ARR = 0xF;       

    // TIM21->DIER |= (TIM_DIER_UIE_Msk);                                  // enable interrupts
    // NVIC_EnableIRQ(TIM21_IRQn); 
    // NVIC_SetPriority(TIM21_IRQn,_TIM21_ISR_PRIORITY);    
    
    TIM21->CR1 |= (TIM_CR1_CEN_Msk);                                    // start the timer

}

int main()
{
    #if DEBUG
        SEGGER_RTT_ConfigUpBuffer(0, NULL, NULL, 0, SEGGER_RTT_MODE_BLOCK_IF_FIFO_FULL);
    #endif
    setup();
    // SEGGER_RTT_printf(0, "%x\r\n", midi_up_preset_msg);
    // SEGGER_RTT_printf(0, "%x\r\n", midi_down_preset_msg);

    // read_midi_channel();
    // SEGGER_RTT_printf(0, "%x\r\n", midi_up_preset_msg);
    // SEGGER_RTT_printf(0, "%x\r\n", midi_down_preset_msg);
    
    // SEGGER_RTT_printf(0, "%x\r\n", midi_down_preset_msg[0]);
    // SEGGER_RTT_printf(0, "%x\r\n", midi_down_preset_msg[1]);
    // SEGGER_RTT_printf(0, "%x\r\n", midi_down_preset_msg[2]);

    [[maybe_unused]] uint32_t tmp = get_clk_freq();
    tmp = get_clk_freq();

    enable_led(false);

    while (1)
    {
        // blinky!
        // toggle_led(0xFFFF);
    }
}


////////////////////////////////
/// Interupt Service Routines
////////////////////////////////

extern "C" 
{

void NMI_Handler(void)
{
    while (1)
    {
        // trouble
    }
}
void HardFault_Handler(void)
{
    while (1)
    {
        // trouble
    }
}
void SVC_Handler(void)
{
    while (1)
    {
        // trouble
    }
}
void PendSV_Handler(void)
{
    while (1)
    {
        // trouble
    }
}
void SysTick_Handler(void)
{
}

}

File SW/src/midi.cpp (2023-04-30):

#include <midi.hpp>
#include <array>
#include <stdint.h>
#include <stm32l011xx.h>
#if DEBUG
    #include <SEGGER_RTT.h>
#endif
#include <led.hpp>

const volatile uint32_t DIPSW_DEBOUNCE_COOLDOWN{ 200 };
volatile uint32_t dipsw_pa0_prev_cnt = 0;
volatile uint32_t dipsw_pa4_prev_cnt = 0;
volatile uint32_t dipsw_pc14_prev_cnt = 0;
volatile uint32_t dipsw_pc15_prev_cnt = 0;
const volatile uint32_t FOOTSW_DEBOUNCE_COOLDOWN{ 100 };
volatile uint32_t footsw_up_prev_cnt = 0;
volatile uint32_t footsw_down_prev_cnt = 0;

// MIDI CC messages - 0xnc, 0xcc, 0xvv 
// LSB first: starting left to right
//   n is the status type (0xB)
//   c is the MIDI channel
//   cc is the controller number (0-127)
//   vv is the controller value (0-127)
// 0x82 is nemesis preset up cmd 
std::array<uint8_t, 3> midi_up_preset_msg{0xB0, 0x82, 0x00};  

// MIDI CC messages - 0xnc, 0xcc, 0xvv 
// LSB first: starting left to right
//   n is the status type (0xB)
//   c is the MIDI channel
//   cc is the controller number (0-127)
//   vv is the controller value (0-127)
// 0x80 is nemesis preset down cmd
std::array<uint8_t, 3> midi_down_preset_msg{0xB0, 0x80, 0x00}; 

uint8_t midi_channel{0};    // only 4 lsb bits used 
#define midi_chan_mask (midi_channel << 0U)
uint8_t midi_preset_counter{8};

// bytes will only be processed by LPUART ISR when counts are zero, so start at non-zero
uint16_t msg_tx_count{0};


enum preset_enum {
    UP_COMMAND,
    DOWN_COMMAND,
    IDLE
};

preset_enum transmit_command_direction = IDLE;

void increment_midi_preset()
{
    if (midi_preset_counter > 0)
    {
        midi_preset_counter--;
        midi_down_preset_msg[2] = midi_preset_counter;
        #if DEBUG
            SEGGER_RTT_printf(0, "DOWN %d\r\n", midi_preset_counter); 
        #endif
        print_midi_msg();
    }    
    transmit_command_direction = DOWN_COMMAND;
}

void decrement_midi_preset()
{
    if (midi_preset_counter < 0xFE)
    {
        midi_preset_counter++;
        midi_up_preset_msg[2] = midi_preset_counter;
        #if DEBUG
            SEGGER_RTT_printf(0, "UP %d\r\n", midi_preset_counter); 
        #endif
        print_midi_msg();
    }
    transmit_command_direction = UP_COMMAND;    
}

void send_midi_bytes()
{
    if (transmit_command_direction == UP_COMMAND)
    {
        // transmit up preset bytes until count = 0
        if (msg_tx_count == 0)
        {
            LPUART1->ICR |= USART_ICR_TCCF_Msk;
        }
        if (msg_tx_count == midi_down_preset_msg.size())
        {
            msg_tx_count = 0;
            LPUART1->CR1 &=  ~( USART_CR1_TXEIE_Msk );                           
        }
        else
        {
            // transfer next byte     
            LPUART1->TDR = (midi_down_preset_msg[msg_tx_count] & 0xFF);       
            msg_tx_count++;
        }
    }

    if (transmit_command_direction == DOWN_COMMAND)
    {
        if (msg_tx_count == 0)
        {
            LPUART1->ICR |= USART_ICR_TCCF_Msk;
        }
        if (msg_tx_count == midi_down_preset_msg.size())
        {
            msg_tx_count = 0;
            LPUART1->CR1 &=  ~( USART_CR1_TXEIE_Msk );                           
        }
        else
        {
            // transfer next byte     
            LPUART1->TDR = (midi_down_preset_msg[msg_tx_count] & 0xFF);       
            msg_tx_count++;
        }
    }    
}

void print_midi_msg()
{
    #if DEBUG
        SEGGER_RTT_printf(0, "midi_down_preset_msg:");
        SEGGER_RTT_printf(0, "0x%x", midi_down_preset_msg[2]);
        SEGGER_RTT_printf(0, "%x", midi_down_preset_msg[1]);
        SEGGER_RTT_printf(0, "%x\r\n", midi_down_preset_msg[0]); 
        SEGGER_RTT_printf(0, "midi_up_preset_msg:");
        SEGGER_RTT_printf(0, "0x%x", midi_up_preset_msg[2]);
        SEGGER_RTT_printf(0, "%x", midi_up_preset_msg[1]);
        SEGGER_RTT_printf(0, "%x\r\n", midi_up_preset_msg[0]);    
    #endif
}

/// @brief Write the 4 LSB according to the dip switch settings
void read_midi_channel()
{
    // PA4  - EXT_MIDI_CH_BIT1
    if (GPIOA->IDR & (GPIO_IDR_ID4_Msk))
    {
        midi_channel |= (1U << 0U);
    }
    // PC14 - EXT_MIDI_CH_BIT2
    if (GPIOC->IDR & (GPIO_IDR_ID14_Msk))
    {
        midi_channel |= (1U << 1U);
    }
    // PC15 - EXT_MIDI_CH_BIT3
    if (GPIOC->IDR & (GPIO_IDR_ID15_Msk))
    {
        midi_channel |= (1U << 2U);
    }    
    // PA0  - EXT_MIDI_CH_BIT4
    if (GPIOA->IDR & (GPIO_IDR_ID0_Msk))
    {
        midi_channel |= (1U << 3U);
    }    

    // most sig. nibble of `midi_channel` should be 0000, so we can shift the 
    // whole byte in without clobbering the existing MSB status bit.
    midi_up_preset_msg[0] |= midi_channel << 0U;
    midi_down_preset_msg[0] |= midi_channel << 0U;
}

////////////////////////////////
/// Interupt Service Routines
////////////////////////////////

extern "C" {
void EXTI4_15_IRQHandler()
{
    // #if DEBUG
    // SEGGER_RTT_printf(0, "EXTI4_15_IRQHandler\r\n");
    // #endif

    // PA9 EXTI - EXT_DOWN_PRESET_SW
    if (EXTI->PR & EXTI_IMR_IM9_Msk)                
    {
        uint32_t tmp_cnt = TIM21->CNT;
        if ((tmp_cnt - footsw_down_prev_cnt) > FOOTSW_DEBOUNCE_COOLDOWN)
        {
            toggle_led();   // visual debug. This should be removed at some point
            increment_midi_preset();
            
            // Enable TXE (tx data reg transferred) interrupts to start the LPUART transmission
            LPUART1->CR1 |=  ( USART_CR1_TXEIE_Msk );   
        }
        else
        {
            // #if DEBUG
            // SEGGER_RTT_printf(0, "Debounced\r\n");
            // #endif
        }
        EXTI->PR |= (EXTI_PR_PIF9_Msk);
        footsw_down_prev_cnt = tmp_cnt;
    }

    // PA10 EXTI - EXT_UP_PRESET_SW
    else if (EXTI->PR & EXTI_IMR_IM10_Msk)         
    {
        uint32_t tmp_cnt = TIM21->CNT;
        if ((tmp_cnt - footsw_up_prev_cnt) > FOOTSW_DEBOUNCE_COOLDOWN)
        {
            toggle_led();   // visual debug. This should be removed at some point
            decrement_midi_preset();
            // Enable TXE (tx data reg transferred) interrupts to start the LPUART transmission
            LPUART1->CR1 |=  ( USART_CR1_TXEIE_Msk );   
        }
        else
        {
            // #if DEBUG
            // SEGGER_RTT_printf(0, "Debounced\r\n");
            // #endif
        }
        EXTI->PR |= (EXTI_PR_PIF10_Msk);            
        footsw_up_prev_cnt = tmp_cnt;
    }
}

void LPUART1_IRQHandler()
{
    
    // if last byte was transferred from TDR to shift register then we are ready to send next byte
    if ((LPUART1->ISR & USART_ISR_TXE) != 0U)
    {
        send_midi_bytes();
    }
}

}

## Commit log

2023-01-06 Add KicadLibrary submodule
2023-01-06 Added kiad project in HW dir
    [CR3Holder002.step, Input.kicad_sch, J Bezel Closed.igs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]
2023-04-09 Updated to kicad 7.0.1, added stm32 doc links into schema page, regen pdf schema
    [Input.kicad_sch, MIDI.kicad_sch, MIDIPresetController.kicad_pcb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]
2023-04-09 added kicad backup files
2023-04-09 refactored led code
2023-04-09 enabled timer
2023-04-14 added exti timer debounce
2023-04-14 exti triggers single uart msg
2023-04-30 moved techdocs
    [Microcontroller.kicad_sch]
2023-04-30 seperated led/tim function
